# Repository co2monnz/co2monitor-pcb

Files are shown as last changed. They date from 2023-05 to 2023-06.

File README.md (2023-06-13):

# co2mon.nz Ventilation Monitor

Inspired by https://github.com/oseiler2/CO2Monitor

## Description

This is a prototype CO2 based ventilation monitor intended for fixed
(wall-mounted) use in standard residential, office and retail type spaces. It
uses the well regards Sensirion SCD40 CO2 sensor as well as a Bosch BME680 for
VOC and barometric pressure measurement and a Sensirion SHT30 for temperature
and humidity.

WiFi connectivity is provided by the main ESP32-S3 processor allowing
measurements to be reported back to the https://co2mon.nz/ web service if
desired.

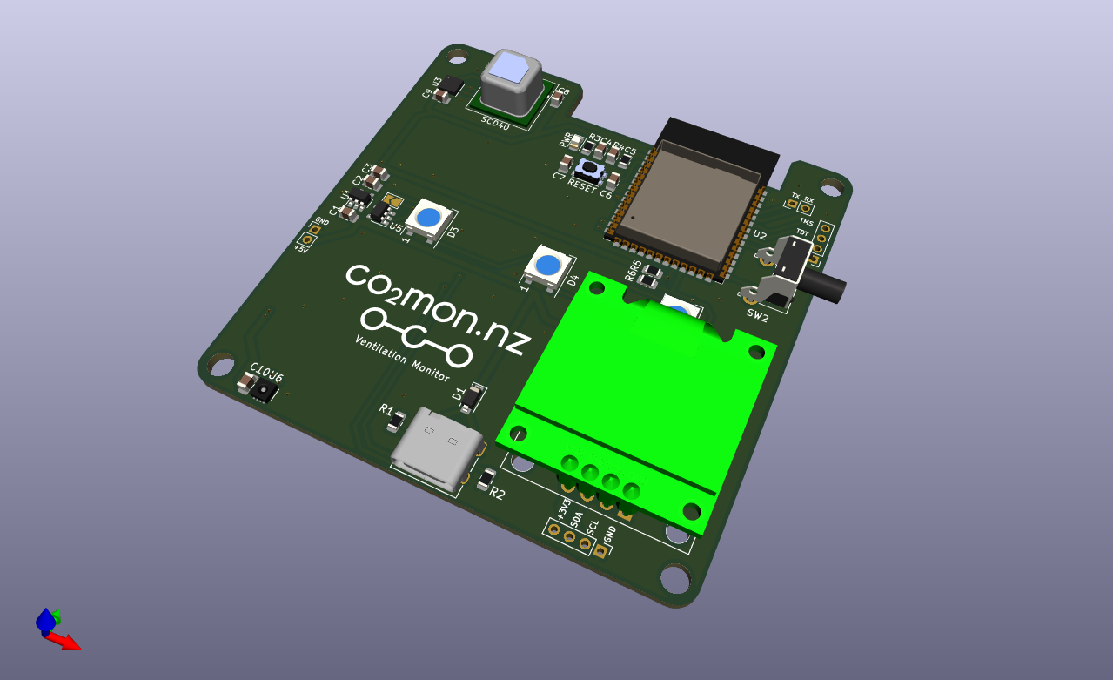
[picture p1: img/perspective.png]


An accompanying 3D printable case design can be found in the
https://github.com/co2monnz/cad repository.

## License, Copyright and Reuse

© 2023 [MKMBA Ltd](https://www.mkmba.nz/).

The design files (e.g. schematics, pcb layout and associated data) in this
repository are available under the terms of the CC-BY-NC license detailed in
the accompanying LICENSE file. 

There doesn't seem to be any perfect way of licensing hadware designs that I've
found yet, so if the CC-BY-NC terms are not suitable for you please get in
touch and I'll generally be fairly wiling to consider other options including
for commercial re-use, etc.

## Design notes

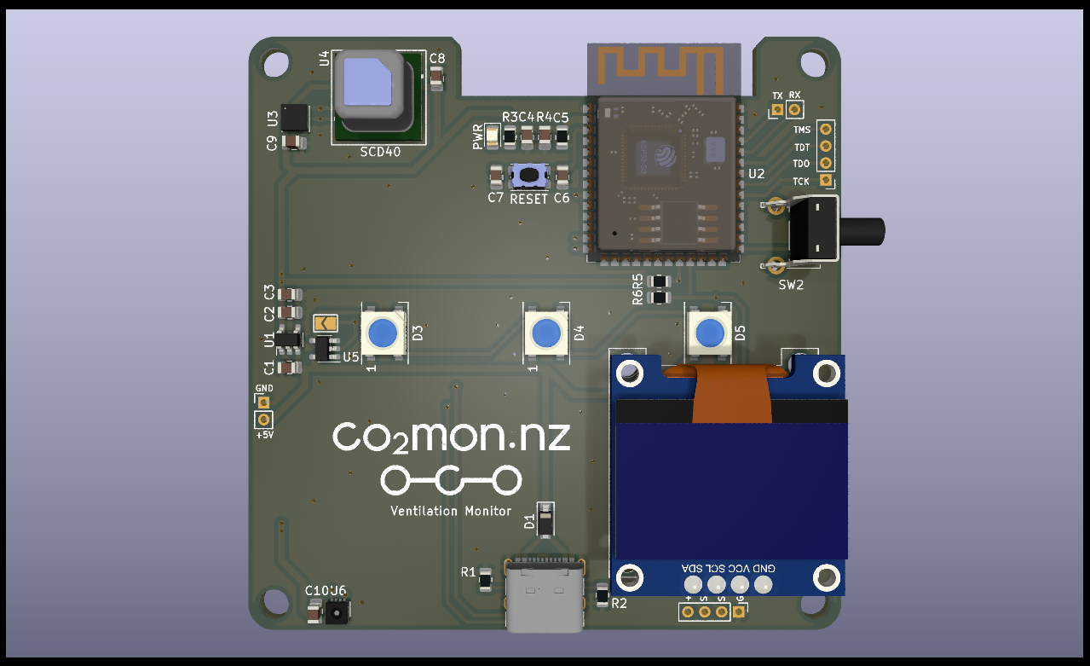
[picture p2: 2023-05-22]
img/top-down.png

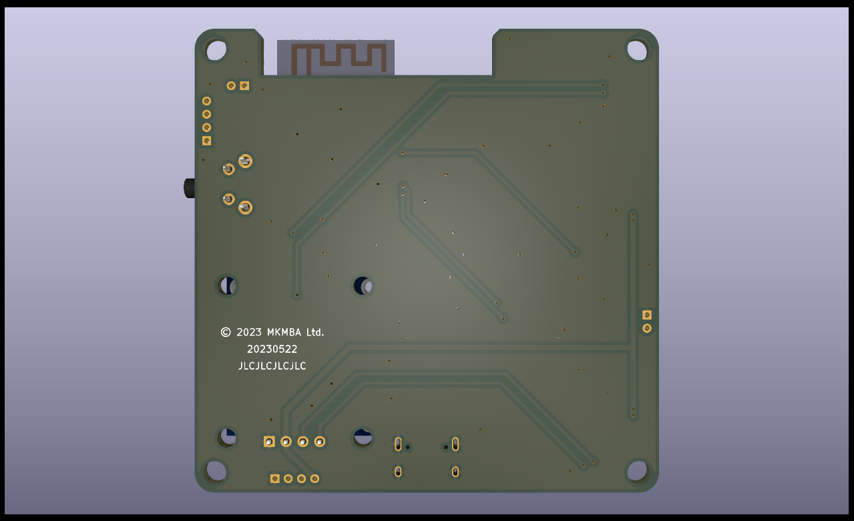
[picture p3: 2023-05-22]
img/bottom.png

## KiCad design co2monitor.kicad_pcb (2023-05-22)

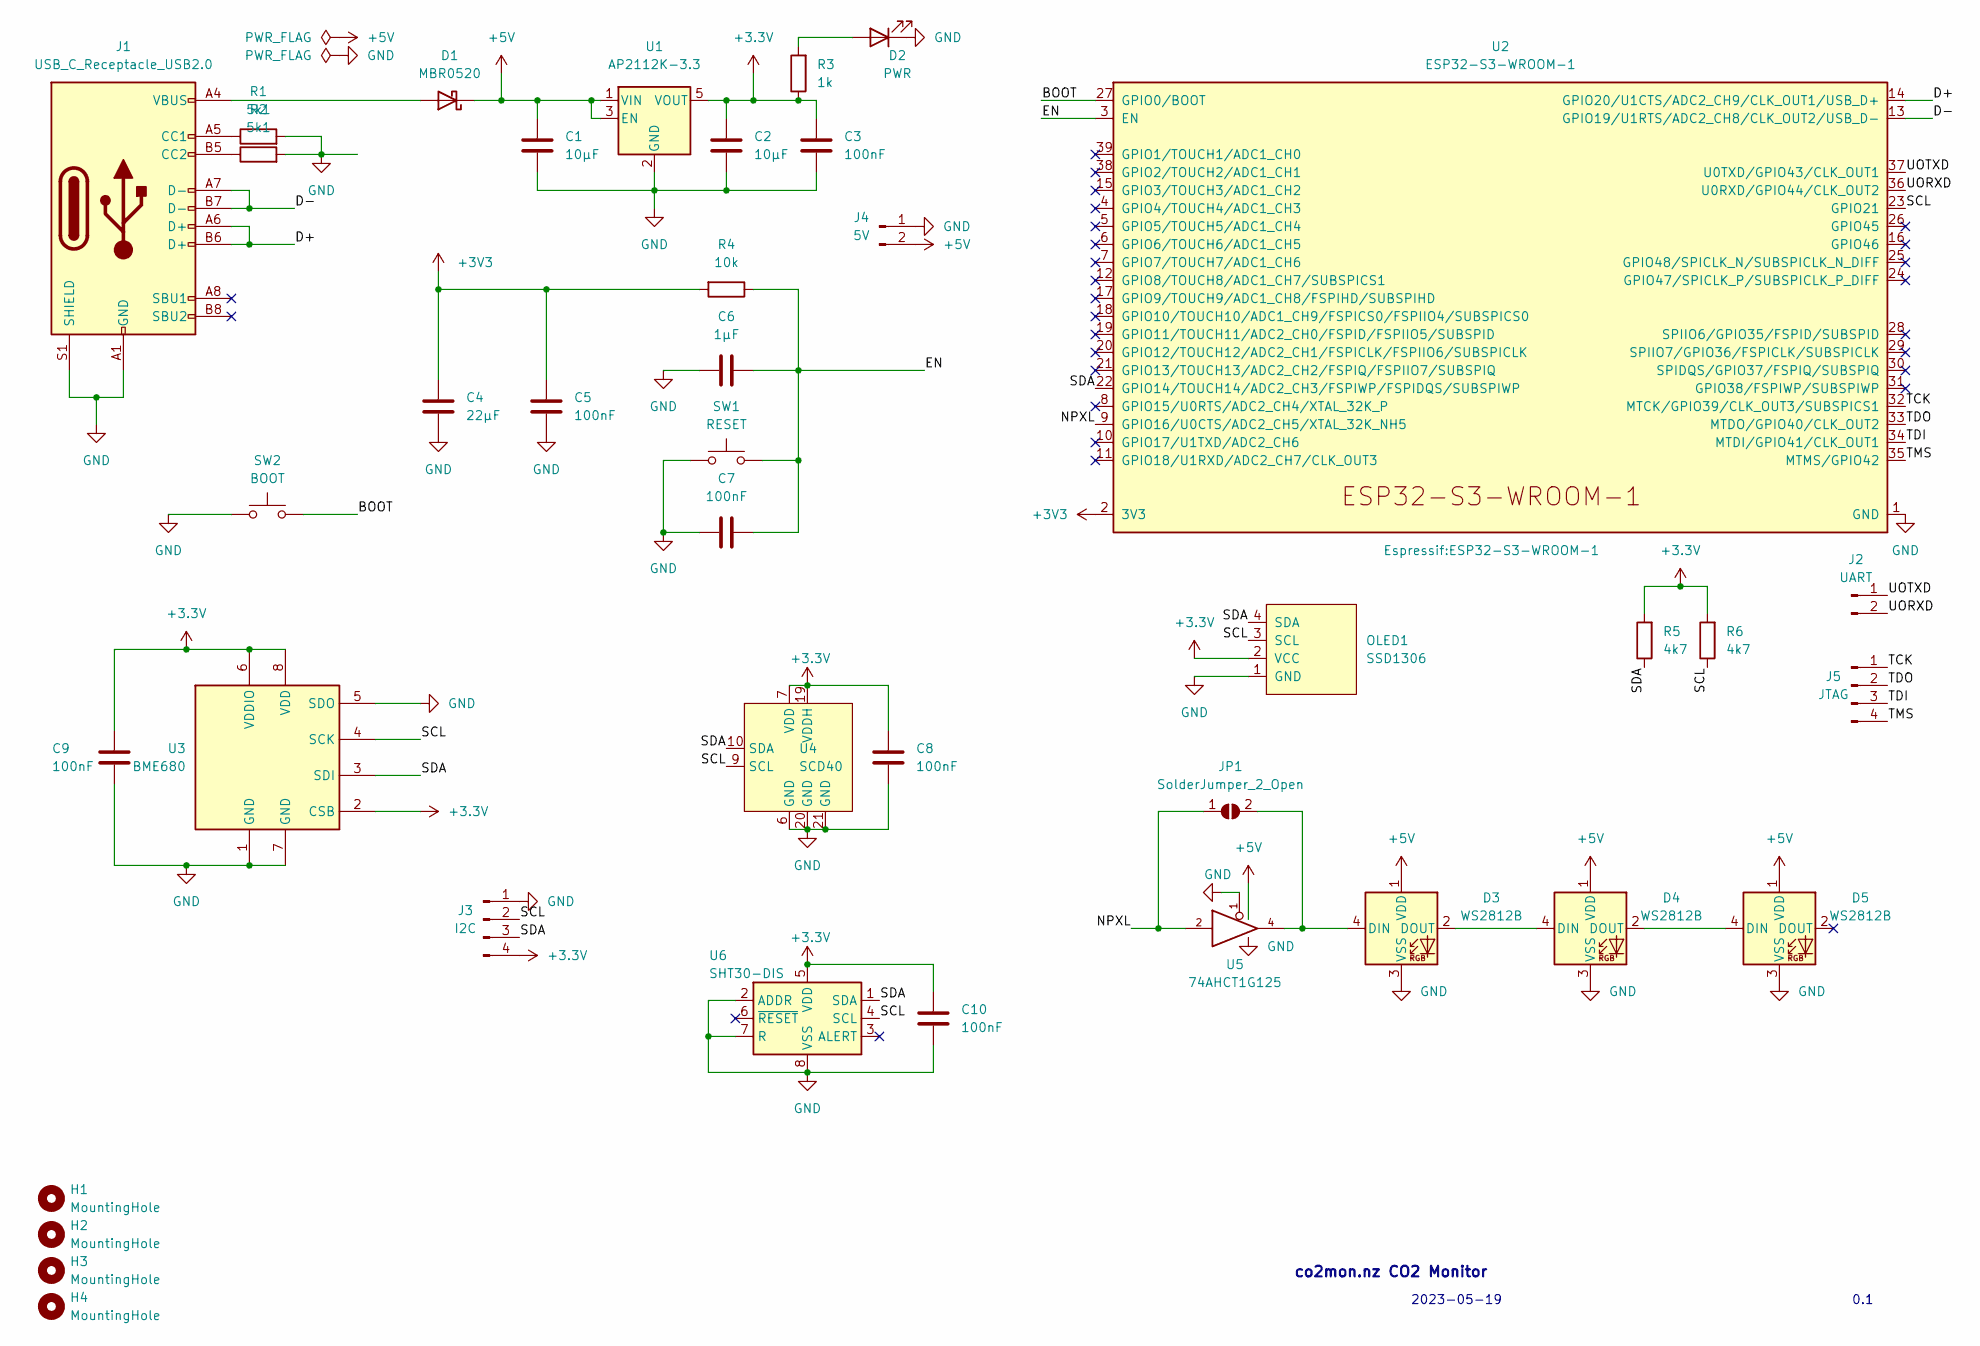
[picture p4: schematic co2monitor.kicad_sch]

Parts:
C1, C2: 10μF; C_0805_2012Metric; LCSC C15850
C3, C5, C7, C8, C9, C10: 100nF; C_0805_2012Metric; LCSC C14663
C4: 22μF; C_0805_2012Metric; LCSC C45783
C6: 1μF; C_0805_2012Metric; LCSC C28323
D1: MBR0520; D_SOD-123; LCSC C908230
D2: PWR; LED_0805_2012Metric; LCSC C84256
D3, D4, D5: WS2812B; LED_WS2812B_PLCC4_5.0x5.0mm_P3.2mm; MPN COM-16346; LCSC C2874885
H1, H2, H3, H4: MountingHole; MountingHole_3.5mm
J1: USB_C_Receptacle_USB2.0; USB_C_Receptacle_XKB_U262-16XN-4BVC11; LCSC C165948
J2: UART; PinHeader_1x02_P2.00mm_Vertical
J3: I2C; PinHeader_1x04_P2.00mm_Vertical
J4: 5V; PinHeader_1x02_P2.00mm_Vertical
J5: JTAG; PinHeader_1x04_P2.00mm_Vertical
JP1: SolderJumper_2_Open; SolderJumper-2_P1.3mm_Open_TrianglePad1.0x1.5mm
OLED1: SSD1306; OLED_128x64_0.96_small
R1, R2: 5k1; R_0805_2012Metric; LCSC C27834
R3: 1k; R_0805_2012Metric; LCSC C17513
R4: 10k; R_0805_2012Metric; LCSC C17414
R5, R6: 4k7; R_0805_2012Metric; LCSC C17673
SW1: RESET; SW_Push_1P1T_NO_CK_KMR2; LCSC C269272
SW2: BOOT; SW_Tactile_SPST_Angled_PTS645Vx83-2LFS; LCSC C221893
U1: AP2112K-3.3; SOT-23-5; LCSC C51118
U2: ESP32-S3-WROOM-1; LCSC C2913198
U3: BME680; Bosch_LGA-8_3x3mm_P0.8mm_ClockwisePinNumbering
U4: SCD40; SCD40-D-R1
U5: 74AHCT1G125; SOT-23-5; LCSC C7484
U6: SHT30-DIS; SHT30_DFN-8-1EP_2.5x2.5mm_P0.5mm_EP1.1x1.7mm; LCSC C77361

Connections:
+5V: C1.2, D1.1 (K), D3.1 (VDD), D4.1 (VDD), D5.1 (VDD), J4.2, U1.1 (VIN), U1.3 (EN), U5.5 (VCC)
/BOOT: SW2.2, U2.27 (GPIO0/BOOT)
/D+: J1.A6 (D+), J1.B6 (D+), U2.14 (GPIO20/U1CTS/ADC2_CH9/CLK_OUT1/USB_D+)
/D-: J1.A7 (D-), J1.B7 (D-), U2.13 (GPIO19/U1RTS/ADC2_CH8/CLK_OUT2/USB_D-)
/EN: C6.1, C7.2, R4.1, SW1.2, U2.3 (EN)
/NPXL: JP1.1 (A), U2.9 (GPIO16/U0CTS/ADC2_CH5/XTAL_32K_NH5), U5.2
/SCL: J3.2, OLED1.3 (SCL), R6.1, U2.23 (GPIO21), U3.4 (SCK), U4.9 (SCL), U6.4 (SCL)
/SDA: J3.3, OLED1.4 (SDA), R5.1, U2.22 (GPIO14/TOUCH14/ADC2_CH3/FSPIWP/FSPIDQS/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), U3.3 (SDI), U4.10 (SDA), U6.1 (SDA)
/TCK: J5.1, U2.32 (MTCK/GPIO39/CLK_OUT3/SUBSPICS1)
/TDI: J5.3, U2.34 (MTDI/GPIO41/CLK_OUT1)
/TDO: J5.2, U2.33 (MTDO/GPIO40/CLK_OUT2)
/TMS: J5.4, U2.35 (MTMS/GPIO42)
/UORXD: J2.2, U2.36 (U0RXD/GPIO44/CLK_OUT2)
/UOTXD: J2.1, U2.37 (U0TXD/GPIO43/CLK_OUT1)
GND: C1.1, C2.1, C3.2, C4.1, C5.2, C6.2, C7.1, C8.1, C9.1, C10.1, D2.1 (K), D3.3 (VSS), D4.3 (VSS), D5.3 (VSS), J1.A1 (GND), J1.A12 (GND), J1.B1 (GND), J1.B12 (GND), J1.S1 (SHIELD), J3.1, J4.1, OLED1.1 (GND), R1.2, R2.2, SW1.1, SW2.1, U1.2 (GND), U2.1 (GND), U2.40 (GND), U2.41 (GND), U3.1 (GND), U3.5 (SDO), U3.7 (GND), U4.6 (GND), U4.20 (GND), U4.21 (GND), U5.1, U5.3 (GND), U6.2 (ADDR), U6.7 (R), U6.8 (VSS), U6.9 (VSS)
unnamed: D1.2 (A), J1.A4 (VBUS), J1.A9 (VBUS), J1.B4 (VBUS), J1.B9 (VBUS)
unnamed: D2.2 (A), R3.2
unnamed: D3.2 (DOUT), D4.4 (DIN)
unnamed: D3.4 (DIN), JP1.2 (B), U5.4
unnamed: D4.2 (DOUT), D5.4 (DIN)
unnamed: J1.A5 (CC1), R1.1
unnamed: J1.B5 (CC2), R2.1

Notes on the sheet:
co2mon.nz CO2 Monitor
0.1
2023-05-19

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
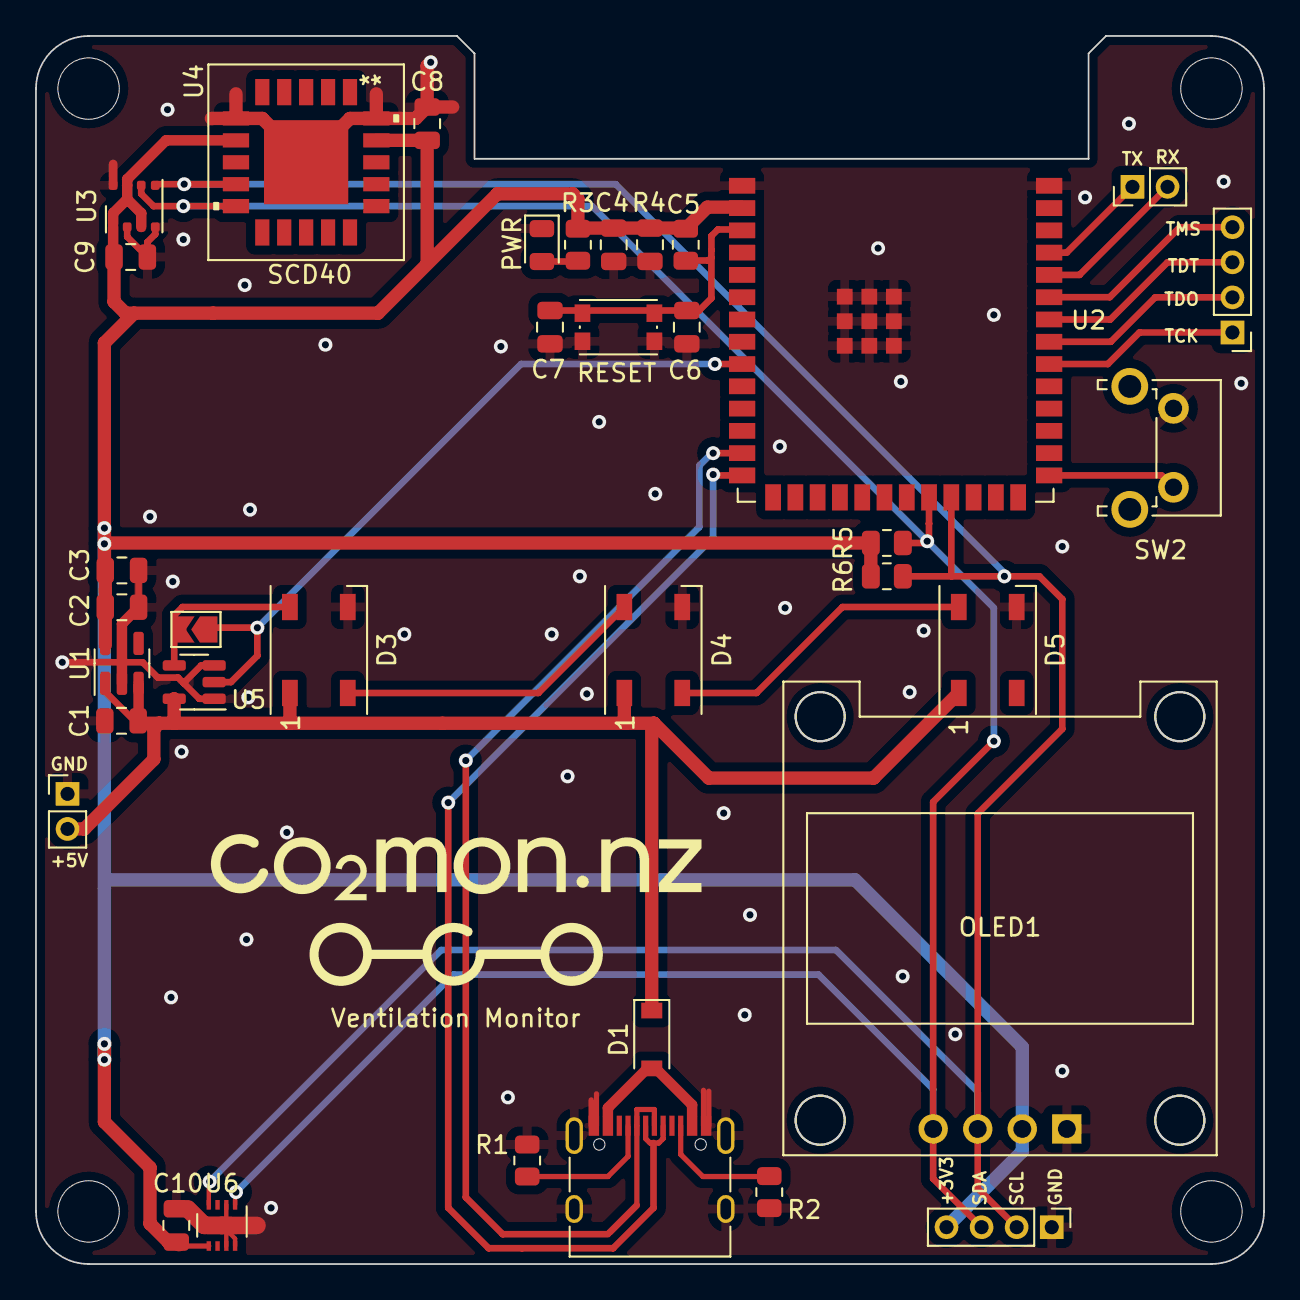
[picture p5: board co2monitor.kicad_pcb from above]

Board: 2 copper layers, 70.0 x 70.0 mm, 40 parts (0 on the bottom side), 23 nets.

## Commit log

2023-05-20 Initial draft design.
    No idea if this will work :)
    [co2monitor.kicad_pcb, co2monitor.kicad_sch]
2023-05-21 Attempt #2
    - Larger board (aesthetics)
    - Add SHT30 for more accurate temperature measurements
    - Larger tracks
    [co2monitor.kicad_pcb, co2monitor.kicad_sch]
2023-05-21 Add logo
    [co2monitor.kicad_pcb]
2023-05-21 Fix neopixel pinout/footprint
    Turns out the NEOPIXEL_THT and WS2812B symbols have differing pinouts,
    the WS2812B one appears to match reality, which required a slight
    re-layout once the associated footprint changed.
    Also fixed/enlarged a few ground tracks in the power-supply noticed
    while inspecting the new area fills.
    Credit to oseiler2 for spotting the pinout issue.
    [co2monitor.kicad_pcb, co2monitor.kicad_sch]
2023-05-21 Tweak a few more ground tracks
    [co2monitor.kicad_pcb]
2023-05-21 Break out various signals to debugging headers
    [co2monitor.kicad_pcb, co2monitor.kicad_sch]
2023-05-21 Flip the screen for better positioning.
    [co2monitor.kicad_pcb, co2monitor.kicad_sch]
2023-05-21 use the mounting holes in the footprint
    We don't need to duplicate these ourselves!
    [co2monitor.kicad_pcb, co2monitor.kicad_sch]
2023-05-21 Add JTAG header
    [co2monitor.kicad_pcb, co2monitor.kicad_sch]
2023-05-21 Don't silkscreen "Antenna Area" outside board
    [co2monitor.kicad_pcb]
2023-05-21 Fix oled text orientation
    [co2monitor.kicad_pcb]
2023-05-21 Fix undersized boot button track
    [co2monitor.kicad_pcb]
2023-05-22 Prepare for fabrication at JLCPCB
    - Assign LCSC part numbers
    - Add copyright/version/order no placeholder to back silkscreen
    [co2monitor.kicad_pcb, co2monitor.kicad_sch]
2023-05-22 -N4 not -N8 WROOM
    [co2monitor.kicad_sch]
2023-06-13 Add link to case design.
